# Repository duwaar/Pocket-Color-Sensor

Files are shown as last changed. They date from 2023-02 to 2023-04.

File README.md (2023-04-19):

### To Do
- Get 8-bit color value from frequency + color selection
- Print RGB hex code
- Match hex code to closest named color
- Design enclosure
- Move OLED screen
- Maybe add LEDs for sanity check
- 

### Lessons Learned
- Solder big components LAST
- Can't desolder SOIC-8 with an iron--hot air rework station necessary
-

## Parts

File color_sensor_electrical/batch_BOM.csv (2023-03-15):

Reference | Qty. (1 Board) | Qty. Total | Value | Footprint | Datasheet | Packaging | S1PN | S1URL
BT1 BT2 | 2 | 20 | CR2032 |  | ~ | bulk | 3046-2032-ND | https://www.digikey.com/en/products/detail/duracell-industrial-operations-inc/2032/13280369
BT3 | 1 | 10 | Battery holder | color_sensor_electrical:Battery_holder_2xCR2032_smd | ~ | bulk | 36-3074-ND | https://www.digikey.com/en/products/detail/keystone-electronics/3074/4499294
C1 C2 C3 C4 C5 | 5 | 50 | 1 uF | Capacitor_SMD:C_0805_2012Metric | ~ | cut-tape | 1276-1066-1-ND | https://www.digikey.com/en/products/detail/samsung-electro-mechanics/CL21B105KAFNNNE/3886724
J1 | 1 | 10 | OLED_header | Connector_PinSocket_1.00mm:PinSocket_1x04_P1.00mm_Vertical | ~ | ~ | ~ | https://www.ebay.com/itm/324467747224
J2 | 1 | 10 | FTDI_header | Connector_PinSocket_1.00mm:PinSocket_1x06_P1.00mm_Vertical | ~ | bulk | S1112EC-06-ND | https://www.digikey.com/en/products/detail/sullins-connector-solutions/PREC006SBAN-M71RC/2774928
R1 | 1 | 10 | 1k | Resistor_SMD:R_0805_2012Metric | ~ | cut-tape | RNCP0805FTD1K00CT-ND | https://www.digikey.com/en/products/detail/stackpole-electronics-inc/RNCP0805FTD1K00/2240229
R2 | 1 | 10 | 10k | Resistor_SMD:R_0805_2012Metric | ~ | cut-tape | RNCP0805FTD10K0CT-ND | https://www.digikey.com/en/products/detail/stackpole-electronics-inc/RNCP0805FTD10K0/2240262
SW1 | 1 | 10 | SW_SPDT | color_sensor_electrical:Switch_1825232-1_SPDT | ~ | bulk | A107673-ND | https://www.digikey.com/en/products/detail/te-connectivity-alcoswitch-switches/1825232-1/4021554
TP1 TP2 TP3 | 3 | 30 | TestPoint | Connector_Pin:Pin_D1.0mm_L10.0mm | ~ | ~ | ~ | ~
U1 | 1 | 10 | ATmega328P-AU | Package_QFP:TQFP-32_7x7mm_P0.8mm | ~ | cut-tape | ATMEGA328-AURCT-ND | https://www.digikey.com/en/products/detail/microchip-technology/ATMEGA328-AUR/2271023
U2 | 1 | 10 | S-1133B50-U5T1U | Package_TO_SOT_SMD:SOT-89-5_Handsoldering | ~ | cut-tape | 1662-2896-1-ND | https://www.digikey.com/en/products/detail/ablic-inc/S-1133B50-U5T1U/6112890
U3 | 1 | 10 | TCS3200D-TR | Package_SO:SOIC-8_3.9x4.9mm_P1.27mm | ~ | ~ | ~ | https://www.ebay.com/itm/334755914584
Y1 | 1 | 10 | Resonator | color_sensor_electrical:Resonator_CSTNE20M0V530000R0_smd_hand-solder | ~ | cut-tape | 490-17953-1-ND | https://www.digikey.com/en/products/detail/murata-electronics/CSTNE20M0V530000R0/8747734

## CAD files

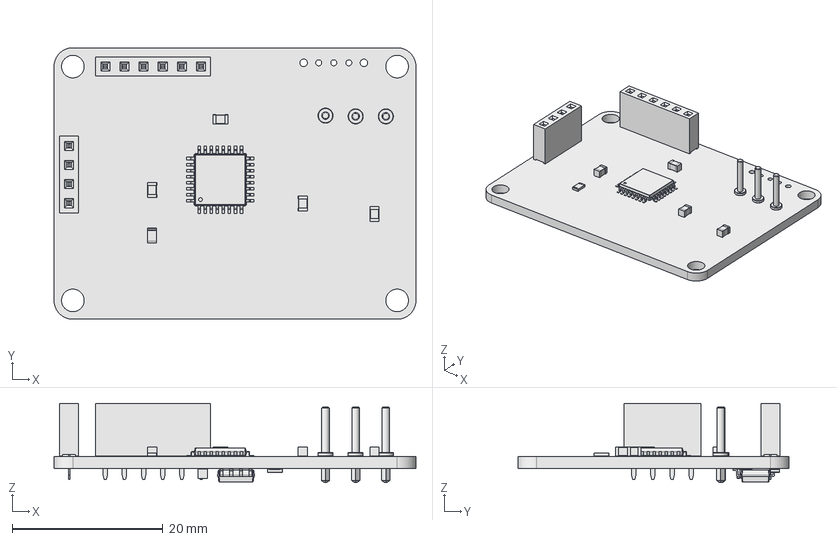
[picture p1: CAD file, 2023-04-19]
CAD_models/color_sensor_assembly.FCStd
48.0 x 36.0 x 10.5 mm

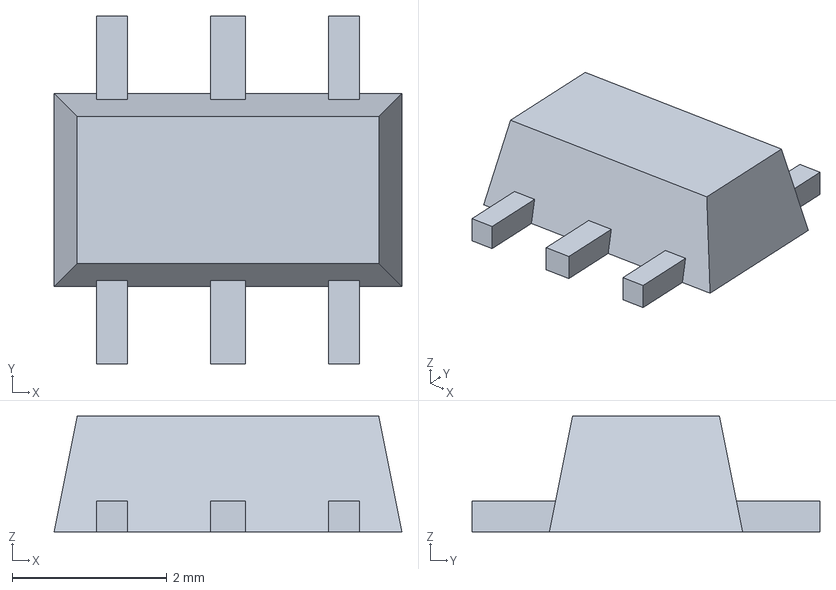
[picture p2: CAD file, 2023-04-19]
color_sensor_electrical/3d_models/S1133_E.step
4.50 x 4.50 x 1.50 mm

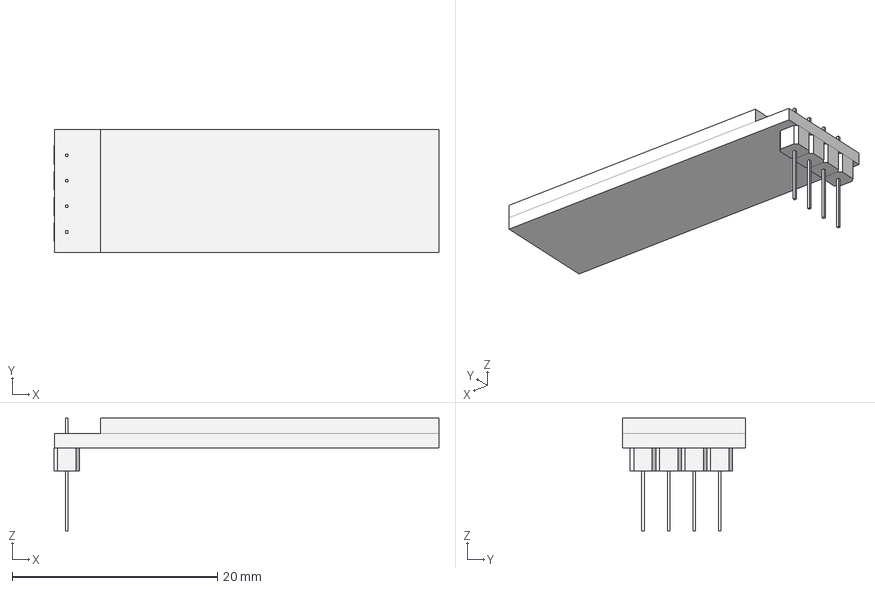
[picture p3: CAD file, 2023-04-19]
color_sensor_electrical/3d_models/OLED_128X32.step
37.5 x 12.0 x 11.0 mm

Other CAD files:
color_sensor_electrical/3d_models/OLED_128x32.FCStd
color_sensor_electrical/3d_models/S1133_E.FCStd

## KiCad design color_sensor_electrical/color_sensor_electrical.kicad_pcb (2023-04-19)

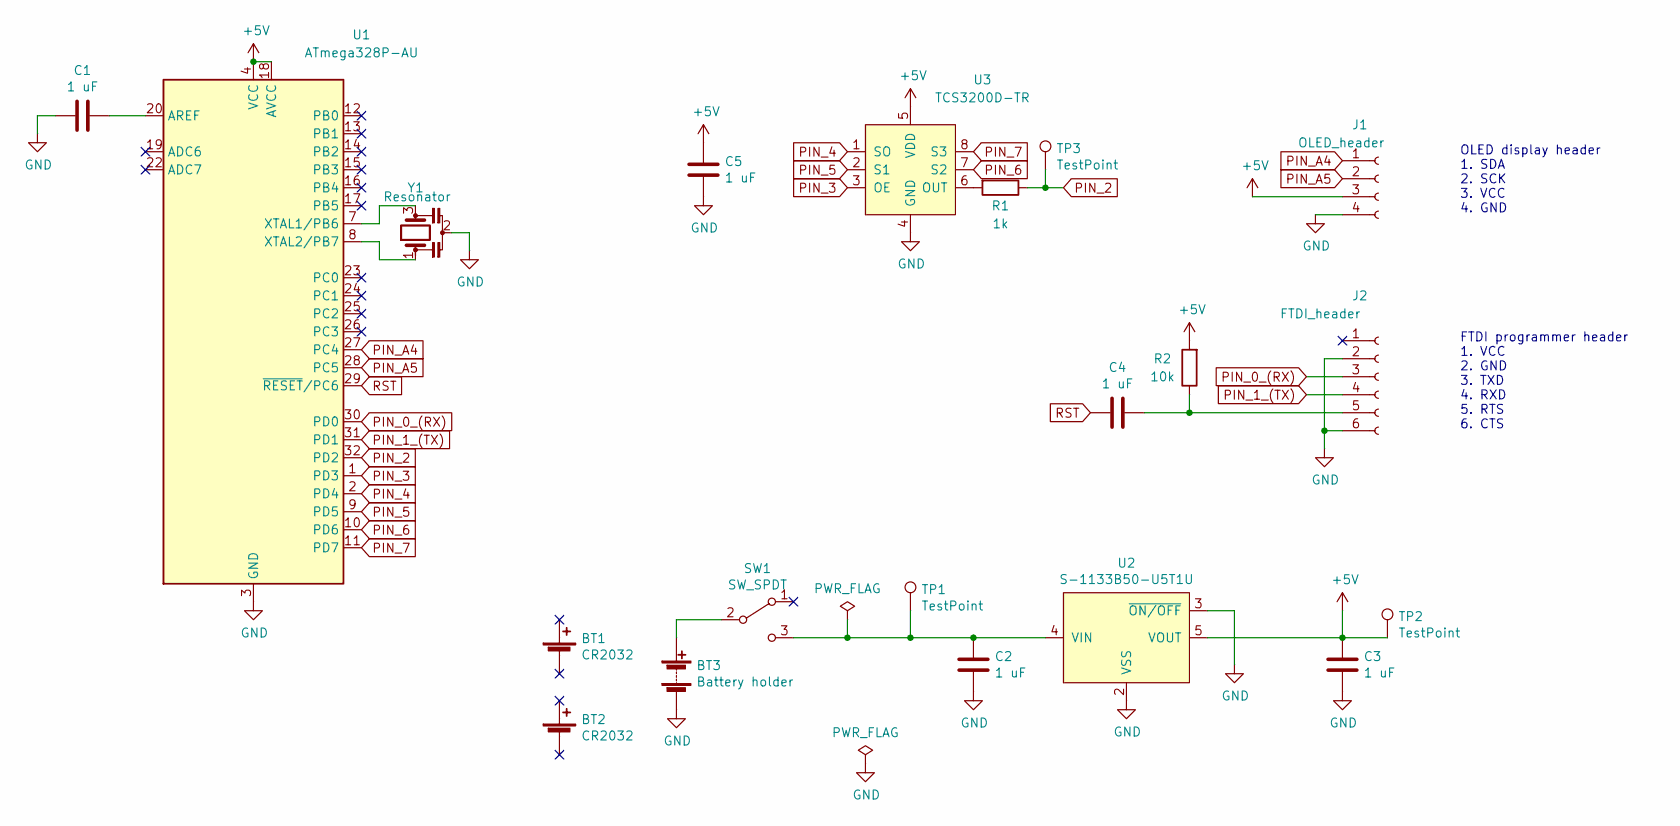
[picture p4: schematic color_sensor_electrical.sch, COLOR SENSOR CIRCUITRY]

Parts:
BT1, BT2: CR2032
BT3: Battery holder; Battery_holder_2xCR2032_smd
C1, C2, C3, C4, C5: 1 uF; C_0805_2012Metric
J1: OLED_header; PinSocket_1x04_P2.54mm_Vertical
J2: FTDI_header; PinSocket_1x06_P2.54mm_Vertical
R1: 1k; R_0805_2012Metric
R2: 10k; R_0805_2012Metric
SW1: SW_SPDT; Switch_1825232-1_SPDT
TP1, TP2, TP3: TestPoint; Pin_D1.0mm_L10.0mm
U1: ATmega328P-AU; TQFP-32_7x7mm_P0.8mm
U2: S-1133B50-U5T1U; SOT-89-5_Handsoldering
U3: TCS3200D-TR; SOIC-8_3.9x4.9mm_P1.27mm
Y1: Resonator; Resonator_CSTNE20M0V530000R0_smd_hand-solder

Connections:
+5V: C3.1, C5.1, J1.3, R2.2, TP2.1, U1.4 (VCC), U1.6 (VCC), U1.18 (AVCC), U2.5 (VOUT), U3.5 (VDD)
GND: BT3.2 (-), C1.2, C2.2, C3.2, C5.2, J1.4, J2.2, J2.6, U1.3 (GND), U1.5 (GND), U1.21 (GND), U2.2 (VSS), U2.3 (~ON/OFF), U3.4 (GND), Y1.2
unnamed: BT3.1 (+), SW1.2 (B)
unnamed: C1.1, U1.20 (AREF)
unnamed: C2.1, SW1.3 (C), TP1.1, U2.4 (VIN)
unnamed: C4.1, J2.5, R2.1
unnamed: R1.2, U3.6 (OUT)
unnamed: U1.7 (XTAL1/PB6), Y1.3
unnamed: U1.8 (XTAL2/PB7), Y1.1
PIN_0_(RX): J2.3, U1.30 (PD0)
PIN_1_(TX): J2.4, U1.31 (PD1)
PIN_2: R1.1, TP3.1, U1.32 (PD2)
PIN_3: U1.1 (PD3), U3.3 (OE)
PIN_4: U1.2 (PD4), U3.1 (SO)
PIN_5: U1.9 (PD5), U3.2 (S1)
PIN_6: U1.10 (PD6), U3.7 (S2)
PIN_7: U1.11 (PD7), U3.8 (S3)
PIN_A4: J1.1, U1.27 (PC4)
PIN_A5: J1.2, U1.28 (PC5)
RST: C4.2, U1.29 (~RESET~/PC6)

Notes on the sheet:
OLED display header 1. SDA 2. SCK 3. VCC 4. GND
FTDI programmer header 1. VCC 2. GND 3. TXD 4. RXD 5. RTS 6. CTS

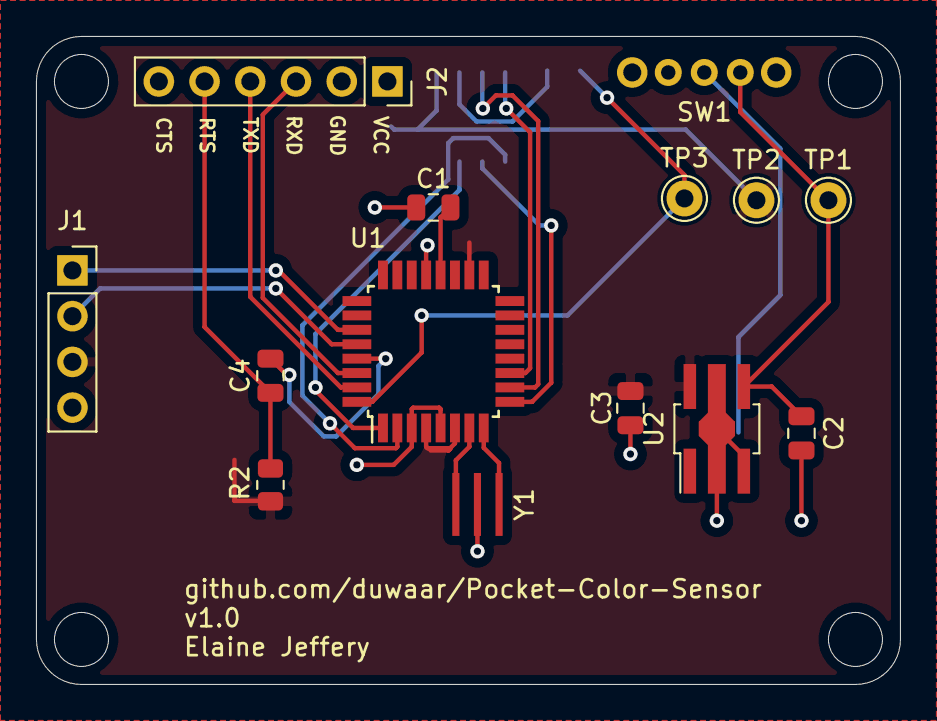
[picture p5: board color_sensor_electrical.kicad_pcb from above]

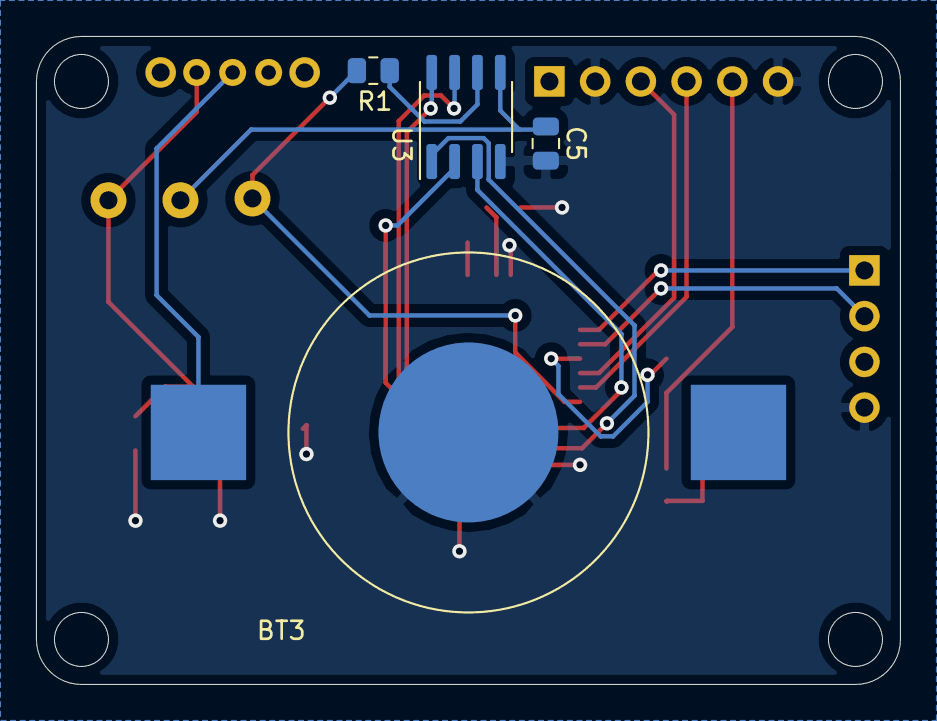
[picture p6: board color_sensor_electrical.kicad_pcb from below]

Board: 2 copper layers, 48.0 x 36.0 mm, 18 parts (4 on the bottom side), 20 nets.

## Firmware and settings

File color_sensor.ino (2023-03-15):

#include <Wire.h>
#include <Adafruit_SSD1306.h>
#include <limits.h>

#define OLED_RESET -1
#define SCREEN_ADDRESS 0x3C
#define SCREEN_WIDTH 128
#define SCREEN_HEIGHT 32
Adafruit_SSD1306 display(SCREEN_WIDTH, SCREEN_HEIGHT, &Wire, OLED_RESET);

#define ROLLING_BUFFER_LENGTH 20
#define COLOR_TIMEOUT 100000

// Pins
const int
    COLOR_OUT = 2,
    OE        = 3,
    S0        = 4,
    S1        = 5,
    S2        = 6,
    S3        = 7;

// Rolling Average
class RollingAverage {
public:
    RollingAverage();
    float update(unsigned int new_value);
    unsigned long sum;
private:
    unsigned int buffer_index;
    unsigned int buffer[ROLLING_BUFFER_LENGTH];
};

RollingAverage::RollingAverage() {
    for (int i = 0; i < ROLLING_BUFFER_LENGTH; i++) {
        buffer[i] = 0;
    }
    sum = 0;
    buffer_index = 0;
}

float RollingAverage::update(unsigned int new_value) {
    sum -= buffer[buffer_index];
    buffer[buffer_index] = new_value;
    buffer_index++;
    if (buffer_index >= ROLLING_BUFFER_LENGTH) {
        buffer_index = 0;
    }
    sum += new_value;
    return sum / ROLLING_BUFFER_LENGTH;
}

RollingAverage
    red_smoothed,
    green_smoothed,
    blue_smoothed;

// Colors
class Color {
public:
    int rgb[3];
    String name;
    Color::Color(int red, int green, int blue, String color_name);
};

Color::Color(int red, int green, int blue, String color_name) {
    rgb[0] = red;
    rgb[1] = green;
    rgb[2] = blue;
    name = color_name;
}

Color VEC_BLUE(6174, 1413, 681, "BLUE");
Color VEC_DARK_GREY(26723, 62717, 61443, "DARK_GREY");
Color VEC_GREEN(1745, 846, 2140, "GREEN");
Color VEC_LIGHT_GREY(1731, 1596, 1735, "LIGHT_GREY");
Color VEC_ORANGE(579, 1195, 1866, "ORANGE");
Color VEC_PURPLE(1268, 1801, 910, "PURPLE");
Color VEC_RED(697, 3802, 3626, "RED");
Color VEC_WHITE(277, 252, 268, "WHITE");
Color VEC_YELLOW(460, 535, 1137, "YELLOW");

Color color_list[] = {
    VEC_BLUE,
    VEC_DARK_GREY,
    VEC_GREEN,
    VEC_LIGHT_GREY,
    VEC_ORANGE,
    VEC_PURPLE,
    VEC_RED,
    VEC_WHITE,
    VEC_YELLOW
};

// Reading from the TCS3200
enum FilterColor_t {RED, GREEN, BLUE, CLEAR};

void setFilterColor(int color) {
    if (color == RED) {
        digitalWrite(S2, LOW);
        digitalWrite(S3, LOW);
    } else if (color == GREEN) {
        digitalWrite(S2, HIGH);
        digitalWrite(S3, HIGH);
    } else if (color == BLUE) {
        digitalWrite(S2, LOW);
        digitalWrite(S3, HIGH);
    } else if (color == CLEAR) {
        digitalWrite(S2, HIGH);
        digitalWrite(S3, LOW);
    }
}

unsigned long readColor(int color) {
    setFilterColor(color);
    unsigned long pulse_length = pulseIn(COLOR_OUT, HIGH, COLOR_TIMEOUT);
    if (pulse_length == 0) {
        
    }
    return light_intensity;
}

// Show the Adafruit splash screen.
void adafruitSplash() {
    display.begin(SSD1306_SWITCHCAPVCC, SCREEN_ADDRESS);
    display.display();
    delay(1500);
}

void setup() {
    Serial.begin(9600);
    Serial.println("Booting.");
    
    // SSD1306 setup
    Serial.println("Adafruit splash screen.");
    adafruitSplash();
    Serial.println("Set typeface.");
    display.setTextSize(1);
    display.setTextColor(SSD1306_WHITE);

    Serial.println("Start display.");
    Serial.println("Clear display.");
    display.clearDisplay();
    Serial.println("Set cursor location.");
    display.setCursor(0,0);
    Serial.println("Render text.");
    display.println("Setting up...");
    Serial.println("Flip display buffer.");
    display.display();

    // TCS3200 setup
    Serial.println("TCS3200 setup.");
    pinMode(COLOR_OUT, INPUT);
    pinMode(OE, OUTPUT);
    pinMode(S0, OUTPUT);
    pinMode(S1, OUTPUT);
    pinMode(S2, OUTPUT);
    pinMode(S3, OUTPUT);

    // Set frequency scale to 20%
    digitalWrite(S0, HIGH);
    digitalWrite(S1, LOW);

    // Enable output
    digitalWrite(OE, LOW);

    // Create smoothing buffers
    Serial.println("Create smoothing buffers.");
    display.println("Create smoothing buffers.");
    for (int i = 0; i < ROLLING_BUFFER_LENGTH; i++) {
        red_smoothed.update(readColor(RED));
        green_smoothed.update(readColor(GREEN));
        blue_smoothed.update(readColor(BLUE));
    }
    Serial.println("blue, red, green");

    display.println("Setup complete.");
    display.display();
    delay(1000);
}

void loop() {
    unsigned long
        raw_red   = readColor(RED),
        raw_green = readColor(GREEN),
        raw_blue  = readColor(BLUE);
    float
        red   = red_smoothed.update(raw_red),
        green = green_smoothed.update(raw_green),
        blue  = blue_smoothed.update(raw_blue);
    Serial.print(raw_blue);
    Serial.print(", ");
    Serial.print(raw_red);
    Serial.print(", ");
    Serial.print(raw_green);
    Serial.println();
    int closest_index = 0;
    float
        least_distance = 1000000.0,
        distance = 0.0;
    for (int i = 0; i < sizeof(color_list) / sizeof(Color); i++) {
        distance = sqrt(
              sq(red   - color_list[i].rgb[0])
            + sq(green - color_list[i].rgb[1])
            + sq(blue  - color_list[i].rgb[2])
            );
        if (distance < least_distance) {
            least_distance = distance;
            closest_index = i;
        }
    }

    display.clearDisplay();
    display.setCursor(0,0);
    display.print(color_list[closest_index].name);
    display.display();
}

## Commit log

2023-02-17 Went back to just Arduino IDE and got it working!
    [black.csv, blue.csv, blue_1.csv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]
2023-03-15 Big commit. Changed firmware and made a PCB.
    [batch_BOM.csv, color_sensor_electrical.kicad_pcb, color_sensor_electrical.sch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]
2023-03-22 Almost ready to order board.
    [color_sensor_electrical.kicad_pcb, color_sensor_electrical.sch]
2023-04-19 Updated readme after first board assembly.
2023-04-19 Added 3D models to PCB.
    [OLED_128X32.step, OLED_128x32.FCStd, S1133_E.FCStd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]
